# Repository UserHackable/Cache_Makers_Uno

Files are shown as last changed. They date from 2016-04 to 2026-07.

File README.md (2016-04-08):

## The Cache Makers Uno project

I created this board in the hopes of using it to teach a group of kids in the [Cache Makers](cachemakers.org) 4H program. 

The build met with mixed success. The board has a large number of solder points to solder in. The older students with a little more hand eye coordination and practice with soldering did ok, the Younger students struggled quite a bit more. 
The board, when completed does provide a functional Arduino Uno compatible device, with some extras for convenience when playing around beginning arduino programming. 

For the next session, I used the [YourDuino RoboRED](http://yourduino.com/sunshop2/index.php?l=product_detail&p=429) which I am a fan of. 
## CacheMakerUno 

### Board dimensions

* (220000, 220068) original units
* (2.2000, 2.2007) inches
* (55.8800, 55.8973) mm

| Front | Back |
| --- | --- |
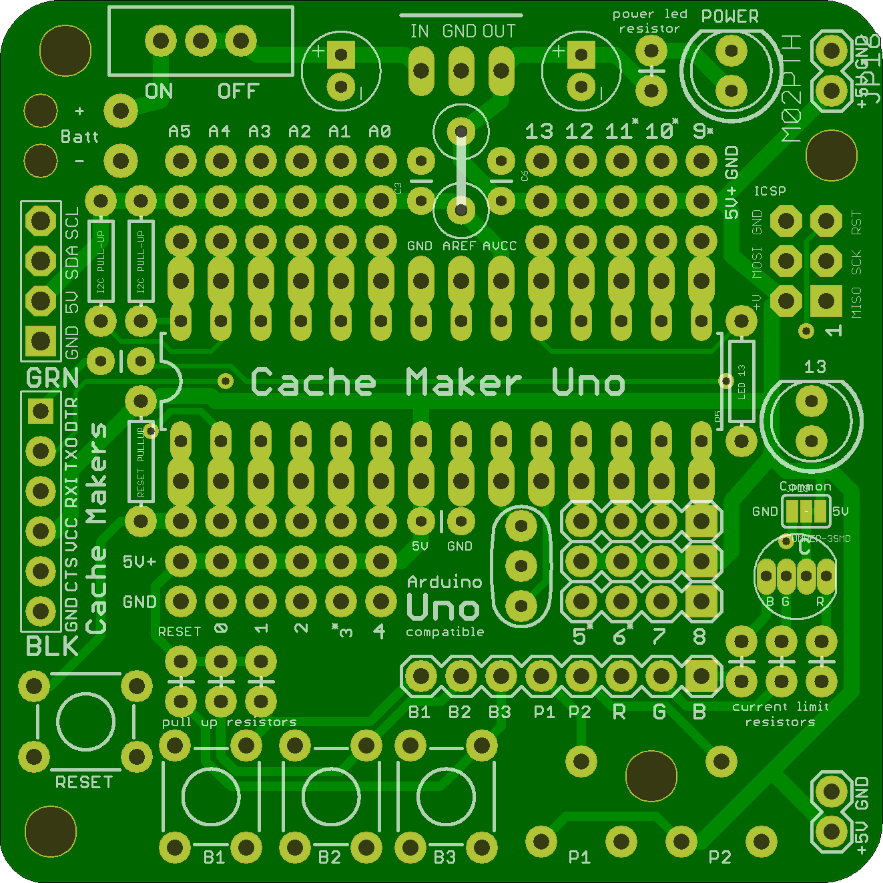
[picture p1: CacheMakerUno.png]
Front
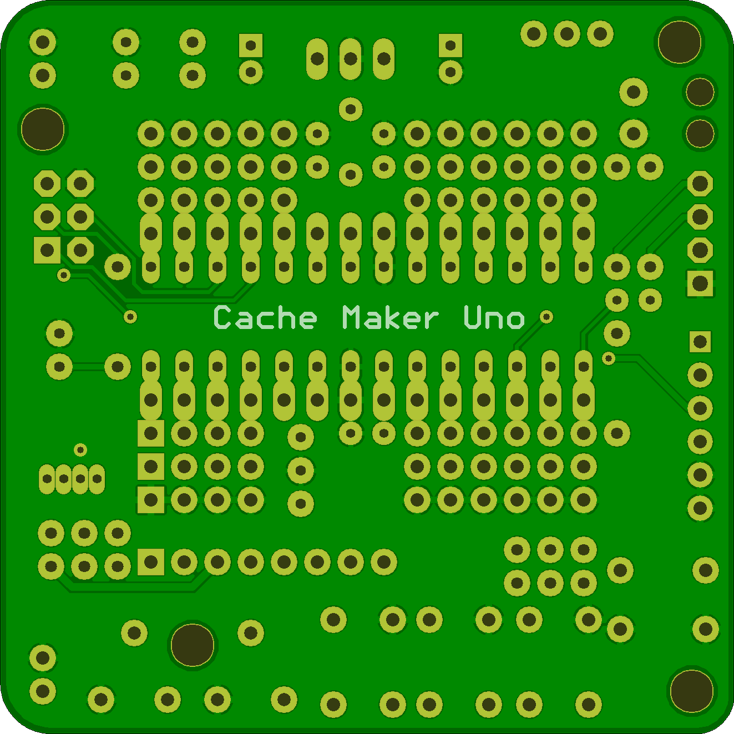
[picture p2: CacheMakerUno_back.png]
Back
|  |  |

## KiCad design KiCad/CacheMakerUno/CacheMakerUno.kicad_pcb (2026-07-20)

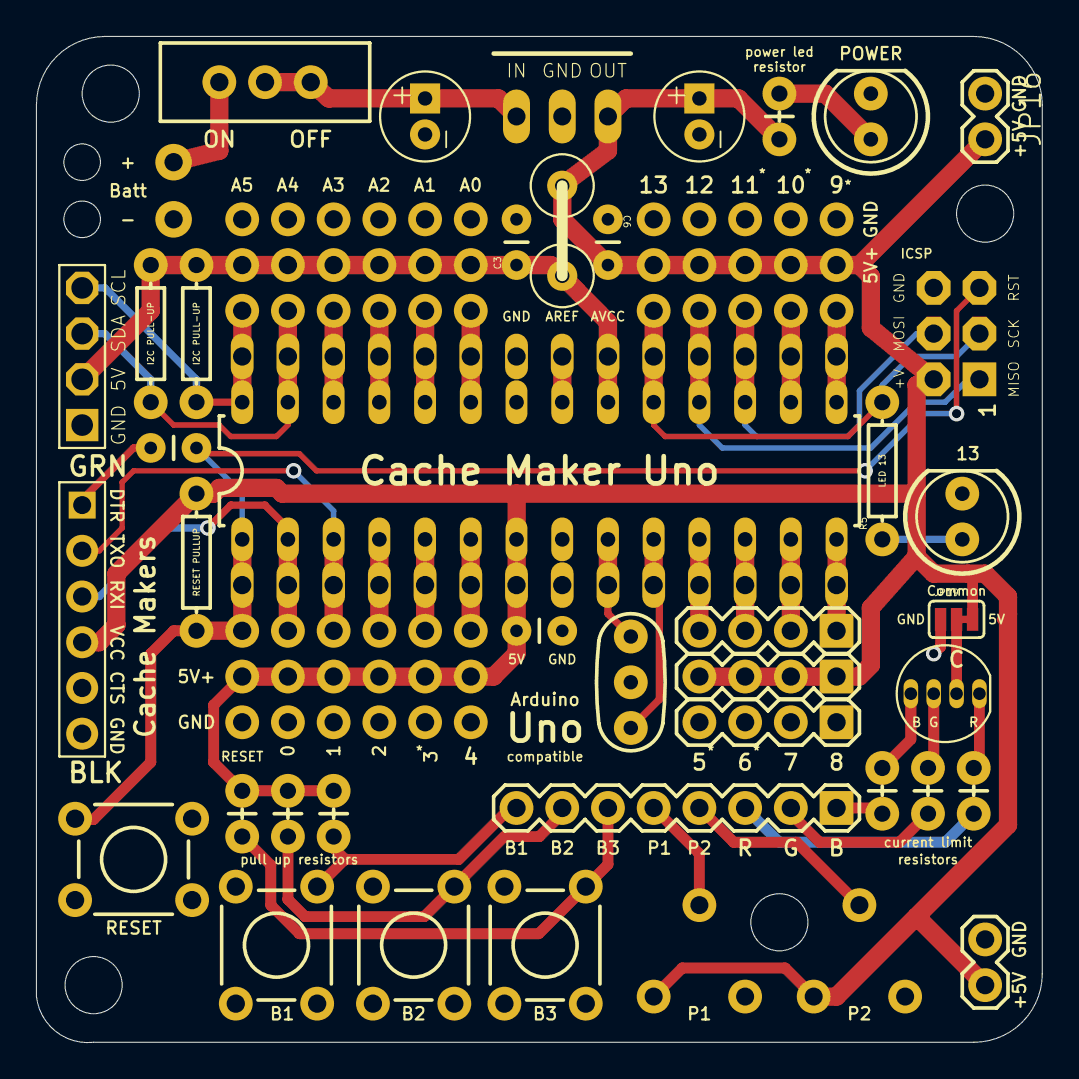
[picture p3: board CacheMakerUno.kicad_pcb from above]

Board: 2 copper layers, 55.9 x 55.9 mm, 58 parts (0 on the bottom side), 43 nets.

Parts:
C1, C2, C3, C6: CAP-PTH-SMALL
C4, C5: CAP-PTH-2MM
D2: LED-RGB-CA-THRUDIFFUSE; LED-RGB-THRU
GND0: M1; M1_NO_STRAIN
IC1: TO-220-REG-BASIC
J1: AVR_SPI_PRG_6LABELED; 2X3-NS
JP1, JP3, JP6: 1X05_NO_SILK
JP2: FTDI_DEVICE; FTDI_DEVICE_SIDE
JP4, JP5: M14HEADER; 1X14-HEADER
JP7, JP8, JP9, JP10, JP11, JP12: 1X06
JP13, JP14, JP15: 1X04
JP16, JP17: M02PTH; 1X02
JP18: 1X08
JP19: JUMPER-3SMD; SJ_3
LED1, LED2: LED5MM
R1, R2, R3, R5: AXIAL-0.3
R4, R6, R7, R8, R9, R10, R11: AXIAL-0.1
RV1, RV2: TRIM_POT
S1, S2, S3, S5: TACTILE-PTH
S4: SWITCH-SPDT
U1: ATMEGA328P_PDIP; DIL28-3
U$1: LFB; ALFB-01
U$2: I2C
UNK_HOLE_0: dummyfp0
UNK_HOLE_1: dummyfp1
UNK_HOLE_2: dummyfp2
UNK_HOLE_3: dummyfp3
V+0: M1; M1_NO_STRAIN
Y1: RESONATOR-PTH

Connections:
5V: C1.1, C4.+, C6.2, D2.2, IC1.3, J1.2, JP2.P$4, JP3.1, JP3.2, JP3.3, JP3.4, JP3.5, JP4.8, JP8.1, JP8.2, JP8.3, JP8.4, JP8.5, JP8.6, JP14.1, JP14.2, JP14.3, JP14.4, JP16.2, JP17.2, JP19.2, JP19.3, R1.P$2, R4.P$2, R9.P$1, R10.P$1, R11.P$1, RV1.2, RV2.2, U1.7, U$1.1
A0: JP5.9, JP7.1, U1.23
A1: JP5.10, JP7.2, U1.24
A2: JP5.11, JP7.3, U1.25
A3: JP5.12, JP7.4, U1.26
A4: JP5.13, JP7.5, R2.P$2, U1.27, U$2.SDA
A5: JP5.14, JP7.6, R3.P$1, U1.28, U$2.SCL
AREF: JP5.7, U1.21
AVCC: C3.1, JP5.6, JP11.1, JP11.2, JP11.3, JP11.4, JP11.5, JP11.6, R2.P$1, R3.P$2, U1.20, U$1.2, U$2.5V
B1: JP18.8, R9.P$2, S1.4
B2: JP18.7, R10.P$2, S2.4
B3: JP18.6, R11.P$2, S3.4
BLUE: JP18.1, R8.P$1
D2: JP4.11, JP10.3, U1.4
D3: JP4.10, JP10.2, U1.5
D4: JP4.9, JP10.1, U1.6
D5: JP4.4, JP13.4, U1.11
D6: JP4.3, JP13.3, U1.12
D7: JP4.2, JP13.2, U1.13
D8: JP4.1, JP13.1, U1.14
D9: JP1.1, JP5.1, U1.15
D10: JP1.2, JP5.2, U1.16
D11: J1.4, JP1.3, JP5.3, U1.17
D12: J1.1, JP1.4, JP5.4, U1.18
D13: J1.3, JP1.5, JP5.5, R5.P$2, U1.19
DTR: C2.1, JP2.P$1
GND: C1.2, C3.2, C4.-, C5.-, C6.1, GND0.P$1, IC1.2, J1.6, JP2.P$5, JP2.P$6, JP4.7, JP5.8, JP6.1, JP6.2, JP6.3, JP6.4, JP6.5, JP9.1, JP9.2, JP9.3, JP9.4, JP9.5, JP9.6, JP12.1, JP12.2, JP12.3, JP12.4, JP12.5, JP12.6, JP15.1, JP15.2, JP15.3, JP15.4, JP16.1, JP17.1, JP19.1, LED1.K, LED2.K, RV1.3, RV2.3, S1.2, S2.2, S3.2, S5.1, S5.2, U1.8, U1.22, U$2.GND, Y1.2
GREEN: JP18.2, R7.P$1
unnamed: LED1.A, R4.P$1
unnamed: LED2.A, R5.P$1
unnamed: D2.1, R6.P$2
unnamed: D2.3, R7.P$2
unnamed: D2.4, R8.P$2
POT1: JP18.5, RV1.1
POT2: JP18.4, RV2.1
RED: JP18.3, R6.P$1
RESET: C2.2, J1.5, JP4.14, JP10.6, R1.P$1, S5.4, U1.1
RX0: JP2.P$3, JP4.13, JP10.5, U1.2
TX1: JP2.P$2, JP4.12, JP10.4, U1.3
VIN: C5.+, IC1.1, S4.2, S4.3
V_BATT: S4.1, V+0.P$1
XTAL1: JP4.6, U1.9, Y1.1
XTAL2: JP4.5, U1.10, Y1.3

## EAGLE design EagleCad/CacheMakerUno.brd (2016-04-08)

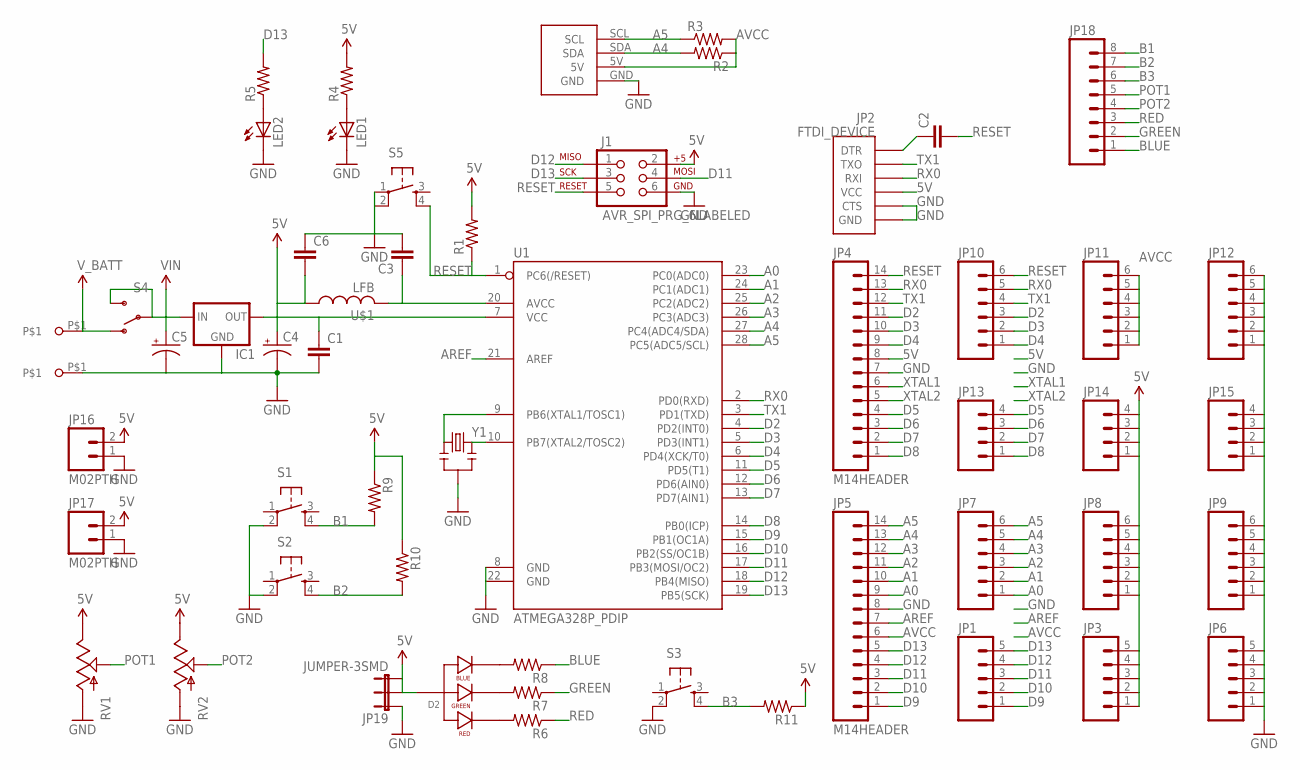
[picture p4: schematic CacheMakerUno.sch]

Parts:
C1, C2, C3, C6: CAPPTH; CAP-PTH-SMALL
C4, C5: CAP_POL2MM; CAP-PTH-2MM
D2: LED-RGB-CA-THRUDIFFUSE; LED-RGB-THRU
GND: M1; M1_NO_STRAIN
IC1: V_REG_78XXBASIC; TO-220-REG-BASIC
J1: AVR_SPI_PRG_6LABELED; 2X3-NS
JP1, JP3, JP6: M05NO_SILK; 1X05_NO_SILK
JP2: FTDI_DEVICE; FTDI_DEVICE_SIDE
JP4, JP5: M14HEADER; 1X14-HEADER
JP7, JP8, JP9, JP10, JP11, JP12: M06SIP; 1X06
JP13, JP14, JP15: M04PTH; 1X04
JP16, JP17: M02PTH; 1X02
JP18: M081X08; 1X08
JP19: JUMPER-3SMD; SJ_3
LED1, LED2: LED5MM
R1, R2, R3, R5: RESISTORAXIAL-0.3; AXIAL-0.3
R4, R6, R7, R8, R9, R10, R11: RESISTORPTH-1/4W-VERT; AXIAL-0.1
RV1, RV2: POTTRIM; TRIM_POT
S1, S2, S3, S5: TAC_SWITCHPTH; TACTILE-PTH
S4: SWITCH-SPDTPTH; SWITCH-SPDT
U1: ATMEGA328P_PDIP; DIL28-3
U$1: LFB; ALFB-01
U$2: I2C
V+: M1; M1_NO_STRAIN
Y1: RESONATORPTH; RESONATOR-PTH

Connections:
5V: C1.1, C4.+, C6.2, D2.2 (ANODE), IC1.3 (OUT), J1.2, JP2.P$4 (VCC), JP3.1, JP3.2, JP3.3, JP3.4, JP3.5, JP4.8, JP8.1, JP8.2, JP8.3, JP8.4, JP8.5, JP8.6, JP14.1, JP14.2, JP14.3, JP14.4, JP16.2, JP17.2, JP19.2, JP19.3, R1.P$2 (2), R4.P$2 (2), R9.P$1 (1), R10.P$1 (1), R11.P$1 (1), RV1.2 (E), RV2.2 (E), U1.7 (VCC), U$1.1
A0: JP5.9, JP7.1, U1.23 (PC0(ADC0))
A1: JP5.10, JP7.2, U1.24 (PC1(ADC1))
A2: JP5.11, JP7.3, U1.25 (PC2(ADC2))
A3: JP5.12, JP7.4, U1.26 (PC3(ADC3))
A4: JP5.13, JP7.5, R2.P$2 (2), U1.27 (PC4(ADC4/SDA)), U$2.SDA
A5: JP5.14, JP7.6, R3.P$1 (1), U1.28 (PC5(ADC5/SCL)), U$2.SCL
AREF: JP5.7, U1.21 (AREF)
AVCC: C3.1, JP5.6, JP11.1, JP11.2, JP11.3, JP11.4, JP11.5, JP11.6, R2.P$1 (1), R3.P$2 (2), U1.20 (AVCC), U$1.2, U$2.5V
B1: JP18.8, R9.P$2 (2), S1.4
B2: JP18.7, R10.P$2 (2), S2.4
B3: JP18.6, R11.P$2 (2), S3.4
BLUE: JP18.1, R8.P$1 (1)
D2: JP4.11, JP10.3, U1.4 (PD2(INT0))
D3: JP4.10, JP10.2, U1.5 (PD3(INT1))
D4: JP4.9, JP10.1, U1.6 (PD4(XCK/T0))
D5: JP4.4, JP13.4, U1.11 (PD5(T1))
D6: JP4.3, JP13.3, U1.12 (PD6(AIN0))
D7: JP4.2, JP13.2, U1.13 (PD7(AIN1))
D8: JP4.1, JP13.1, U1.14 (PB0(ICP))
D9: JP1.1, JP5.1, U1.15 (PB1(OC1A))
D10: JP1.2, JP5.2, U1.16 (PB2(SS/OC1B))
D11: J1.4, JP1.3, JP5.3, U1.17 (PB3(MOSI/OC2))
D12: J1.1, JP1.4, JP5.4, U1.18 (PB4(MISO))
D13: J1.3, JP1.5, JP5.5, R5.P$2 (2), U1.19 (PB5(SCK))
DTR: C2.1, JP2.P$1 (DTR)
GND: C1.2, C3.2, C4.-, C5.-, C6.1, GND.P$1, IC1.2 (GND), J1.6, JP2.P$5 (CTS), JP2.P$6 (GND), JP4.7, JP5.8, JP6.1, JP6.2, JP6.3, JP6.4, JP6.5, JP9.1, JP9.2, JP9.3, JP9.4, JP9.5, JP9.6, JP12.1, JP12.2, JP12.3, JP12.4, JP12.5, JP12.6, JP15.1, JP15.2, JP15.3, JP15.4, JP16.1, JP17.1, JP19.1, LED1.K (C), LED2.K (C), RV1.3 (A), RV2.3 (A), S1.2, S2.2, S3.2, S5.1, S5.2, U1.8 (GND), U1.22 (GND), U$2.GND, Y1.2
GREEN: JP18.2, R7.P$1 (1)
unnamed: LED1.A, R4.P$1 (1)
unnamed: LED2.A, R5.P$1 (1)
unnamed: D2.1 (RED_CATHODE), R6.P$2 (2)
unnamed: D2.3 (GREEN_CATHODE), R7.P$2 (2)
unnamed: D2.4 (BLUE_CATHODE), R8.P$2 (2)
POT1: JP18.5, RV1.1 (S)
POT2: JP18.4, RV2.1 (S)
RED: JP18.3, R6.P$1 (1)
RESET: C2.2, J1.5, JP4.14, JP10.6, R1.P$1 (1), S5.4, U1.1 (PC6(/RESET))
RX0: JP2.P$3 (RXI), JP4.13, JP10.5, U1.2 (PD0(RXD))
TX1: JP2.P$2 (TXO), JP4.12, JP10.4, U1.3 (PD1(TXD))
VIN: C5.+, IC1.1 (IN), S4.2, S4.3 (S)
V_BATT: S4.1 (O), V+.P$1
XTAL1: JP4.6, U1.9 (PB6(XTAL1/TOSC1)), Y1.1
XTAL2: JP4.5, U1.10 (PB7(XTAL2/TOSC2)), Y1.3

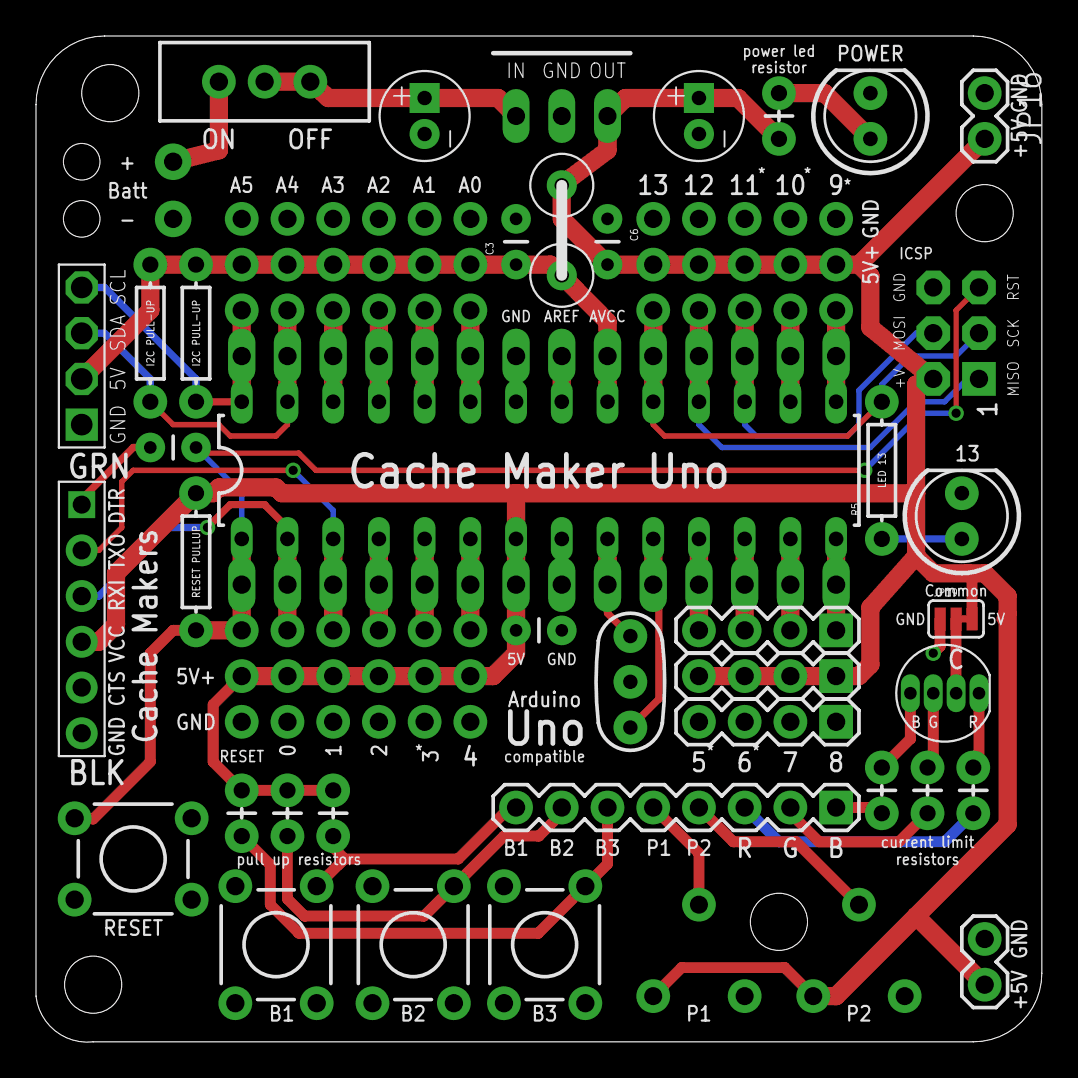
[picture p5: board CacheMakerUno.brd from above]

Board: 2 copper layers, 55.9 x 55.9 mm, 54 parts (0 on the bottom side), 43 nets.

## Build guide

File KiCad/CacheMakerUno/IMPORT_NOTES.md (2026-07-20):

# First-pass KiCad import: CacheMakerUno

- **Source board:** `Cache_Makers_Uno/EagleCad/CacheMakerUno.brd`
- **Source schematic:** `Cache_Makers_Uno/EagleCad/CacheMakerUno.sch`
- **PCB import:** OK (kicad-cli pcb import)
- **Schematic import:** not automated — use KiCad GUI: File → Import Non-KiCad Project → EAGLE Project
- **Date:** 2026-07-19
- **KiCad:** 10.0.4 (`kicad-cli`)

Automated pipeline converts **boards** via `kicad-cli pcb import --format eagle`.
KiCad 10.0.4 has no headless Eagle **schematic** import (`kicad-cli sch` has no `import`;
no Python `SCH_IO_MGR` module shipped). Open the Eagle `.sch` + `.brd` pair in the GUI
importer when you need a linked schematic, or re-import into this folder.

Validate with DRC/ERC before fab. Do not treat this tree as fab-ready.

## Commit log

2026-07-20 Archive Eagle CAD sources and artifacts under EagleCad/
    Move schematics, boards, libraries, previews, gerber zips, and
    Eagle-era build helpers into EagleCad/ so KiCad can live beside them.
    [CacheMakerUno.brd, CacheMakerUno.sch]
2026-07-20 Add first-pass KiCad import under KiCad/
    Automated conversion from EagleCad/ sources. Validate before fab use.
    [CacheMakerUno.kicad_pcb]

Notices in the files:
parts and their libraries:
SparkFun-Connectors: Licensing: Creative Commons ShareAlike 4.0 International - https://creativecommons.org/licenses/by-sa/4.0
